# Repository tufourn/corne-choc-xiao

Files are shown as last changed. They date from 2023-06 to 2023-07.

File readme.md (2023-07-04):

# Choc-spaced Corne keyboard with XIAO BLE and LIR2032
* Latest gerbers: [Gerbers](https://github.com/tufourn/corne-choc-xiao/blob/main/corne-choc-xiao-gerbers.zip?raw=true)
* Interactive bill of materials: [iBOM](https://htmlpreview.github.io/?https://github.com/tufourn/corne-choc-xiao/blob/main/bom/ibom.html)

## PCB

A choc-spaced Corne PCB modified to support LIR2032 batteries and XIAO BLE microcontroller.

Ordering from [JLCPCB](https://www.jlcpcb.com) will cost about $8 + shipping.

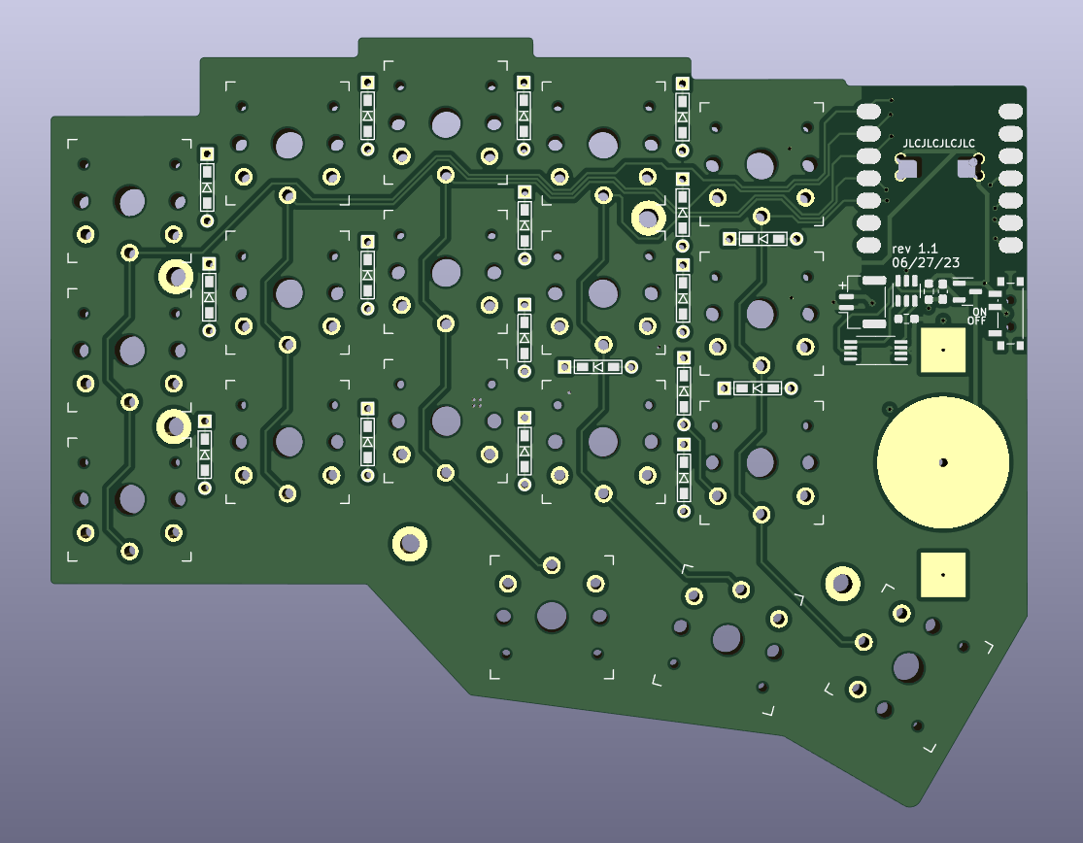
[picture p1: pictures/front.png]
front


## Bill of materials

| Name | Qty | Package | Value | Description |
| ---- | --- | --- | ----- |--- |
| U1 | 1 | SMD | MCU | XIAO BLE |
| U2 | 1 | SOT-23-6| DW01A |Battery protection IC |
| U3 | 1 | TSSOP-8 | FS8205A | Dual N-Channel MOSFET |
| C1 | 1 | 0603 | 100n | SMD Capacitor |
| R1 | 1 | 0603 | 100R | SMD Resistor |
| R2 | 1 | 0603 | 1k | SMD Resistor |
| Q1 | 1 | SOT-23  | SI2302 | N-channel MOSFET for reverse polarity protection |
| S1 | 1 | SMD | SPDT | 7 pin SMD SPDT Switch |
| J1 | 1 | SMD | JST-GH | JST-GH 2 pin Horizontal connector |
| BT1  | 1 | SMD | LIR2032 | LIR2032 Battery Retainer |
| D1-36| 36  | SOT-123 | 1n4148 | Diodes for keyboard matrix |
| SW1-36 | 36| THT | PG1350 | Kailh Choc Switches |

* If using LiPo battery, only solder U1, J1 and S1. The rest of the components are for protecting the LIR2032 and are therefore not needed. Make sure you're connecting the battery correctly.
* If using LIR2032, don't solder J1.
* Either SMD or THT diodes can be used.

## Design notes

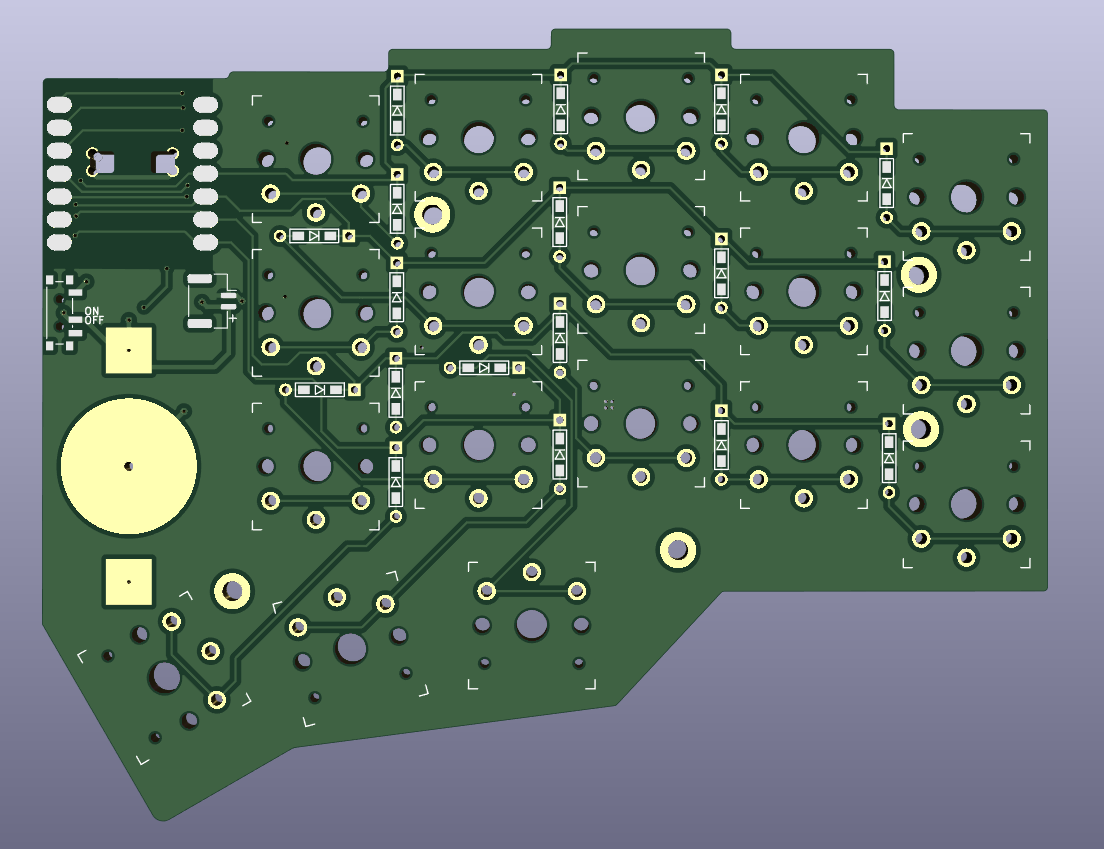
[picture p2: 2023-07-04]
pictures/back.png

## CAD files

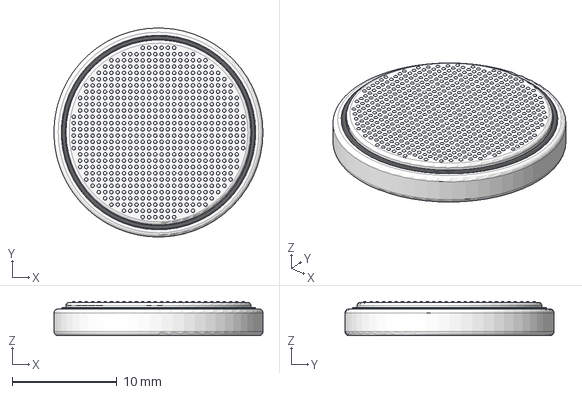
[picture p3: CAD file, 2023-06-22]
symbols/Battery/CR2032.step
20.0 x 20.0 x 3.30 mm

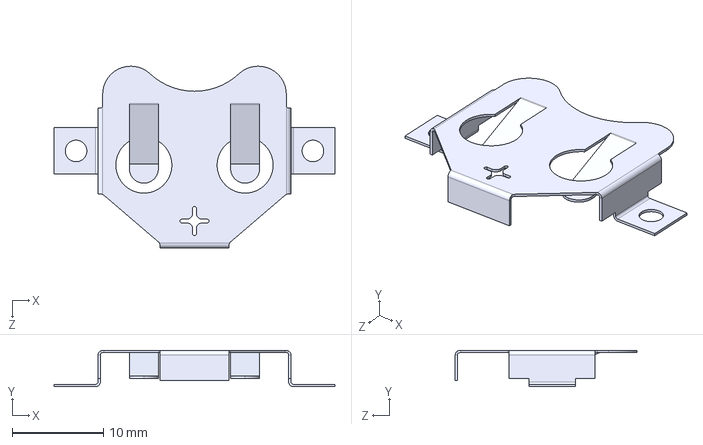
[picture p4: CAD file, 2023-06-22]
symbols/Battery/3002.step
30.7 x 3.96 x 19.9 mm

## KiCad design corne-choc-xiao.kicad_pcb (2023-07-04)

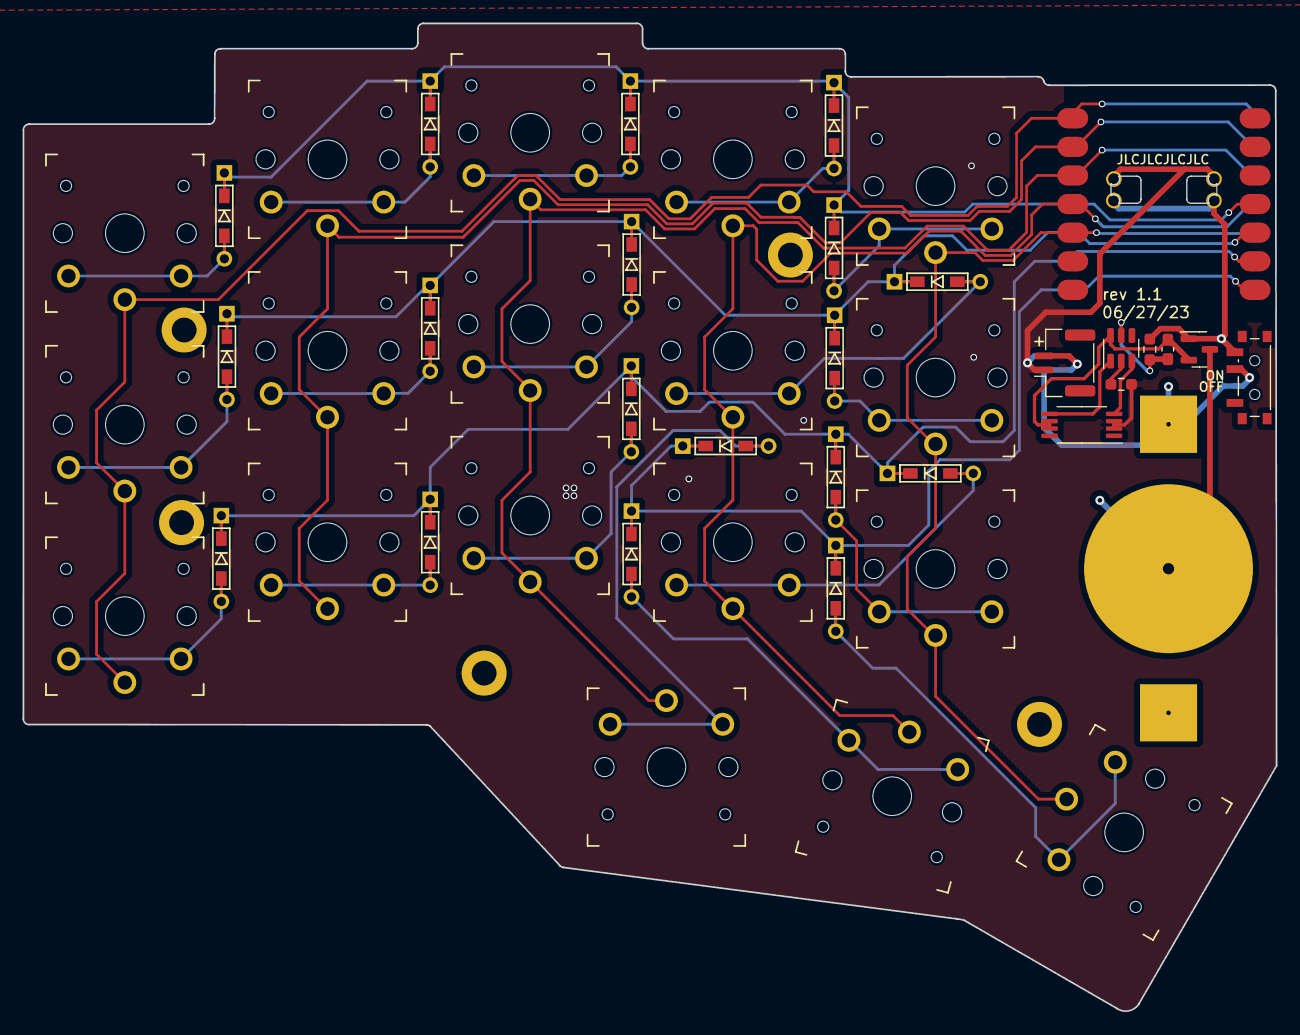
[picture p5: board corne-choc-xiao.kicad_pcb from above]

Board: 2 copper layers, 111.3 x 87.7 mm, 49 parts (0 on the bottom side), 36 nets.

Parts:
BT1: LIR2032; BAT_3002
C1: 100n; C_0603_1608Metric_Pad1.08x0.95mm_HandSolder
D2, D3, D4, D5, D6, D8, D9, D10, D11, D12, D14, D15, D16, D17, D18, D19, D20, D21: D; D3_TH_SMD
J1: LiPo; JST_GH_SM02B-GHS-TB_1x02-1MP_P1.25mm_Horizontal
Q1: SI2302; SOT-23
R1: 100R; R_0603_1608Metric_Pad0.98x0.95mm_HandSolder
R2: 1k; R_0603_1608Metric_Pad0.98x0.95mm_HandSolder
S1: SW_SPDT; SW_SPDT_PCM12
SW2, SW3, SW4, SW5, SW6, SW8, SW9, SW10, SW11, SW12, SW14, SW15, SW16, SW17, SW18, SW19, SW20: SW_PUSH; SW_PG1350_reversible_b2
SW21: SW_PUSH; SW_PG1350_15_reversible_b2
U1: xiao-ble; xiao-ble-tht-cutout
U2: DW01; SOT-23-6
U3: FS8205A; TSSOP-8_4.4x3mm_P0.65mm
h2, h2#2, h2#3: h2; LEGO_HOLE

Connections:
BAT+: Q1.1 (G), R1.2, S1.3 (C), U1.19 (BAT)
BAT-: C1.2, Q1.2 (S), U2.6 (GND), U3.6 (S2), U3.7 (S2)
GND: J1.1, R2.2, U1.20 (GND), U3.2 (S1), U3.3 (S1)
unnamed: D2.2 (A), SW2.2
unnamed: D3.2 (A), SW3.2
unnamed: D4.2 (A), SW4.2
unnamed: D5.2 (A), SW5.2
unnamed: D6.2 (A), SW6.2
unnamed: D8.2 (A), SW8.2
unnamed: D9.2 (A), SW9.2
unnamed: D10.2 (A), SW10.2
unnamed: D11.2 (A), SW11.2
unnamed: D12.2 (A), SW12.2
unnamed: D14.2 (A), SW14.2
unnamed: D15.2 (A), SW15.2
unnamed: D16.2 (A), SW16.2
unnamed: D17.2 (A), SW17.2
unnamed: D18.2 (A), SW18.2
unnamed: D19.2 (A), SW19.2
unnamed: D20.2 (A), SW20.2
unnamed: D21.2 (A), SW21.2
unnamed: BT1.P2, J1.2, S1.2 (B)
unnamed: BT1.N, Q1.3 (D)
unnamed: R2.1, U2.2 (CS)
unnamed: U2.3 (OC), U3.4 (G1)
unnamed: U2.1 (OD), U3.5 (G2)
unnamed: C1.1, R1.1, U2.5 (VCC)
col1: SW2.1, SW8.1, SW14.1, U1.1 (A2/0.02_H)
col2: SW3.1, SW9.1, SW15.1, U1.2 (A4/0.03_H)
col3: SW4.1, SW10.1, SW16.1, SW19.1, U1.3 (A10/0.28)
col4: SW5.1, SW11.1, SW17.1, SW20.1, U1.4 (A11/0.29)
col5: SW6.1, SW12.1, SW18.1, SW21.1, U1.5 (A8_SDA/0.04_H)
row0: D2.1 (K), D3.1 (K), D4.1 (K), D5.1 (K), D6.1 (K), U1.11 (A6_MOSI/1.15)
row1: D8.1 (K), D9.1 (K), D10.1 (K), D11.1 (K), D12.1 (K), U1.10 (A5_MISO/1.14)
row2: D14.1 (K), D15.1 (K), D16.1 (K), D17.1 (K), D18.1 (K), U1.9 (A7_SCK/1.13)
row3: D19.1 (K), D20.1 (K), D21.1 (K), U1.8 (B9_RX/1.12)

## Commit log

2023-06-27 fix battery protection circuit
    [corne-choc-xiao.kicad_pcb, corne-choc-xiao.kicad_sch]
2023-07-04 added readme and ibom
    [corne-choc-xiao.kicad_pcb, corne-choc-xiao.kicad_sch]
